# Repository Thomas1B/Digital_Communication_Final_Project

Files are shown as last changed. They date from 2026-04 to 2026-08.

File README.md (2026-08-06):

# ECET 251 Digital Communications — Final Project

**Camosun College — Trades & Technology — Winter 2026**

## Overview

A wireless link between two Arduinos over a 433 MHz ASK "transparent" RF module pair. The transmitter reads a potentiometer, Manchester-encodes the value along with a checksum, and sends it over the air at 300 baud. The receiver decodes the signal, verifies the checksum, and uses the value to set the brightness of an LED via PWM.

All data processing (encoding, framing, error detection) is done in software on the microcontrollers — the RF modules just carry the baseband signal.

## How it works

**Transmitter (`TX.ino`)**
- Reads a potentiometer on `A7`, mapped from the 10-bit ADC range down to 8 bits.
- On a button press (pin 3), builds a 3-byte message: `[length, pot value, checksum]`, where the checksum is the sum of the first two bytes.
- Sends the array via `man.transmitArray()` at `MAN_300` (300 baud) on pin 9.
- Green LED (pin 4) indicates the system is ready to transmit; blue LED (pin 5) flashes to confirm a transmission was sent.
- A 2-second cooldown between transmissions prevents button-mash spamming.

**Receiver (`RX.ino`)**
- Listens on pin 2 via `man.beginReceiveArray()`.
- On receipt of a complete 3-byte message, recalculates the checksum from the first two bytes and compares it to the third.
- If it matches, the potentiometer value is written out as a PWM signal to an LED on pin 5 (brightness control) and a success counter increments; otherwise the message is dropped and an error counter increments.
- Green status LED (pin 4) shows receiver activity, dimming briefly while a message is processed.

**Manchester encoding (`manchester.h` / `Manchester.cpp`)**
- Third-party library ([mchr3k/arduino-libs-manchester](https://github.com/mchr3k/arduino-libs-manchester)) used for the Manchester encode/decode and timer-based bit recovery on the ATmega328.
- Each transmission begins with a training preamble (14 zero-bits + a start bit) so the receiver's AGC can lock onto the signal before the actual payload is decoded.

## Files

| File | Description |
|---|---|
| `TX.ino` | Transmitter sketch (potentiometer read, button trigger, message send) |
| `RX.ino` | Receiver sketch (message decode, checksum check, LED PWM output) |
| `manchester.h` | Manchester library header (third-party, see credit above) |
| `Manchester.cpp` | Manchester library implementation (third-party, see credit above) |
| `ECET_251_FINAL_REPORT.docx` | Full project report/datasheet (block diagram, schematics, RF characteristics, calculations) |
| `ECET251_Final_Project_Overview_-_2026W.pdf` | Original assignment/rubric from the instructor |

## Hardware

- 2x Arduino (or compatible ATmega328-based board)
- 433 MHz ASK TX/RX module pair
- Potentiometer, pushbutton, status/output LEDs, pull-down and current-limiting resistors, smoothing capacitors

See the full report for the bill of materials, schematics, and measured RF characteristics (bandwidth, EIRP, minimum electric field at the receiver, bit error rate, etc.).

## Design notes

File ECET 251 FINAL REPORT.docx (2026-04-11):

# ECET 251 FINAL REPORT

Members: Faith Thurrott, Thomas Bourgeois, Andrew Goertzen

Instructor: Phil Vreugdenhil

Date: April 10th, 2026

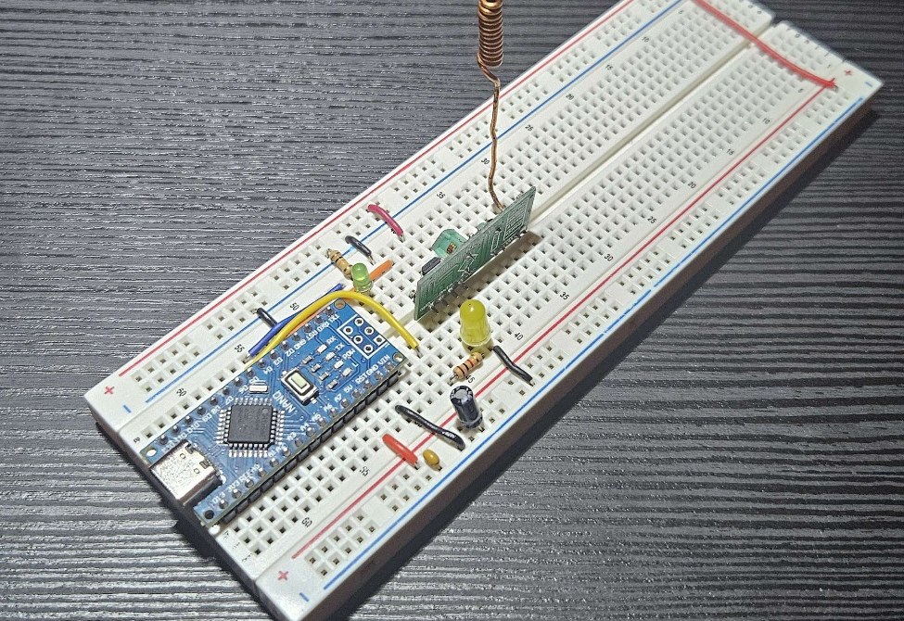
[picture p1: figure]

Figure 1: Receiver Circuit

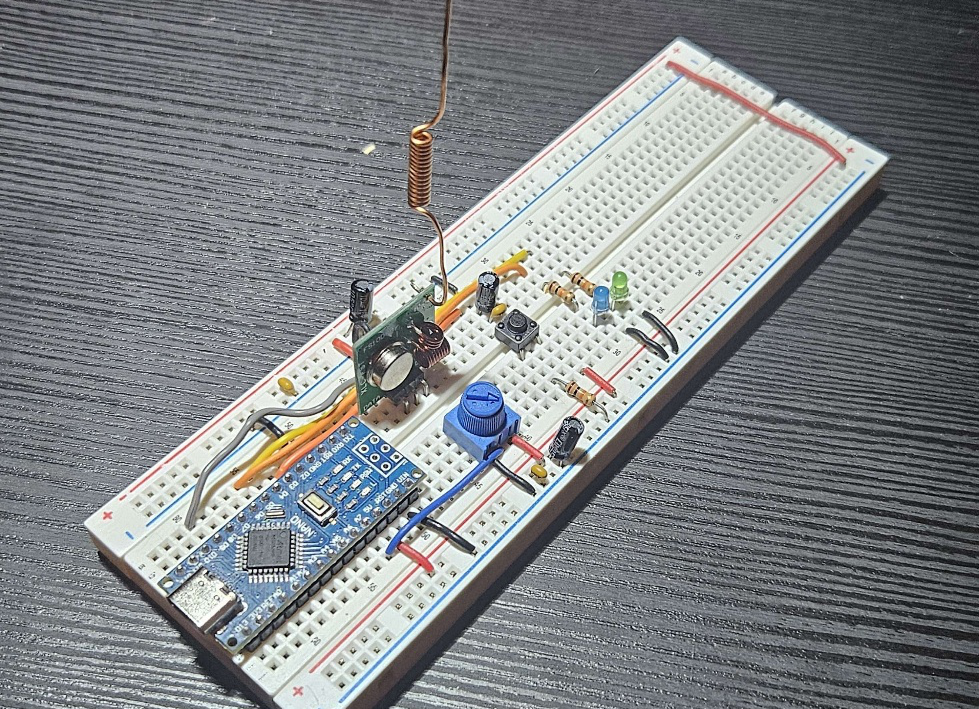
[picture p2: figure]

Figure 2 :Transmitter Circuit

# Project Overview

- Create a wireless system using a microprocessor and TX, Rx modules
- Create a protocol for the system
- Test the communication system
- Document the system

# Project GitHub Repo

https://github.com/Thomas1B/Digital_Communication_Final_Project

# System Description

The following block diagram shows the overall structure of the system, including the main components and signal flow between the transmitter (Tx) and receiver (Rx). The dotted lines represent power, the dashed line represent wireless transmission, and the solid lines represent signals between components.

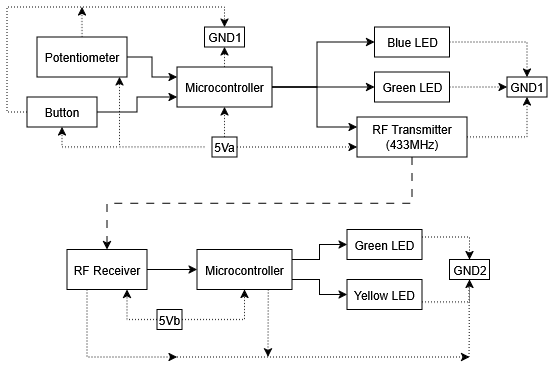
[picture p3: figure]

Figure 3 System Block Diagram

Note: 5Va, 5Vb, GND1, and GND2 are to signify that these two systems are powered separately. They can be power via the USB connection or the Vin pin of the microcontroller.

(5V and GND are the from the internal regulator of the controller).

# Hardware Components

Table 1: BOM: Bill of Materials for Transmitter and Receiver Circuits

Component | Quantity | Specification
Arduino Nano | 2 | 5V microcontroller board. Note 10-bit ADC and 8bit DAC resolution.
Transmitter Module | 1 | 433 MHz RF transmitter module 5Vdc
Receiver Module | 1 | 433 MHz Receiver module. 5Vdc.
Potentiometer | 1 | 10kΩ Pot. (Larger value gives more control)
Button | 1 | Momentary Tactile Switch
LEDS | 4 | 1 Blue LED. 2 Green LEDs, 1 Yellow LED
Resistor | 5 | 1 x 10kΩ, 4 x 1kΩ resistors
Polarized capacitor | 6 | > 4.7uF capacitance
Capacitor | 6 | ≤ 0.1uF non polarized capacitor.

Capacitors are used to smooth the button and potentiometer signals, as well as stabilize power for the transmitter and receiver. While not strictly required, they help reduce noise and improve debouncing. A 10kΩ resistor is used as a pull-down for the button. The 1kΩ resistors can be adjusted to change brightness, make sure the current does not exceed 20 mA. Certain pins of the Arduino are necessary to use, for example PWM pins for the transmitter and to adjust led brightness on the receiver.

# Data Table

Table 2: Collected and Calculated Data

Parameter | Measurement
Bandwidth | 1250Hz
Range limit | 11ft
Min EF at Receiver | 97.4mV/m
Carrier Frequency | 433MHz
Data Rate | 300 Baud Manchester Encoded
Data Format | potentiometer: 10 bit mapped to 8bit, Transmitted data: 3x8bits, Received data: 3x8bits
Operating Voltages | 5 Volts
Power levels | 2.5 Watts
EIRP | 3.36nW
BER | 0.00028%

# Transmitter

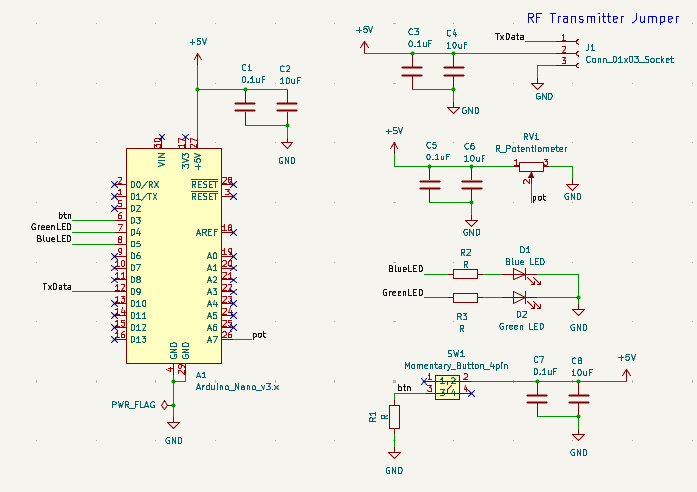
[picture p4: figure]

Figure 4 Schematic of the Transmitter Circuit

The transmitter (Tx) side is designed to read a potentiometer value and send it to the receiver (Rx) using Manchester encoded communication. The potentiometer value is read from an analog pin; when the button is pressed, a 3 x 8-bit byte message is created. The first byte contains the message length, the second byte contains the mapped potentiometer value (since the ADC reads 10bits and the receiver can only transmit 8 bits bytes, also the DAC is only 8bits too), and the third byte contains a checksum for error detection. The checksum is calculated by adding the first two bytes. The data is then sent to the TX module using a PWM pin at a data rate of 300 baud. A green LED indicates when the system is on and ready to transmit, and a blue LED flashes after a message is sent. A timing delay is used so the transmitter does not repeatedly send messages too quickly.

## Transmitter Software Flowchart

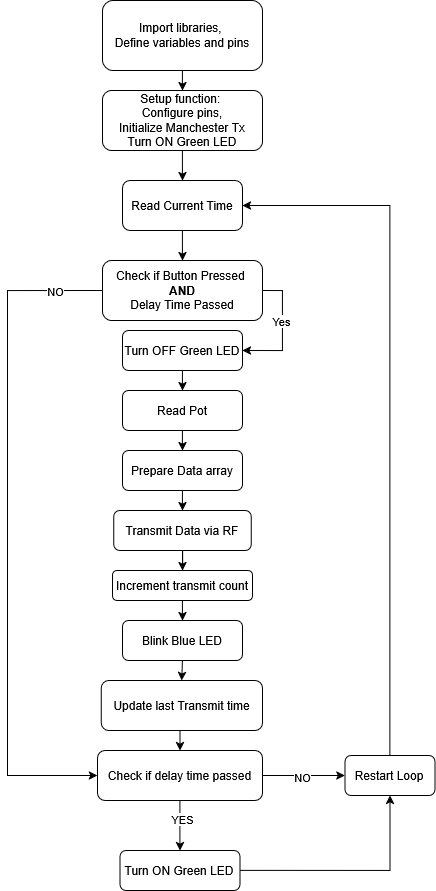
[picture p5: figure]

Figure 6 Transmitter Software Flowchart

# Receiver

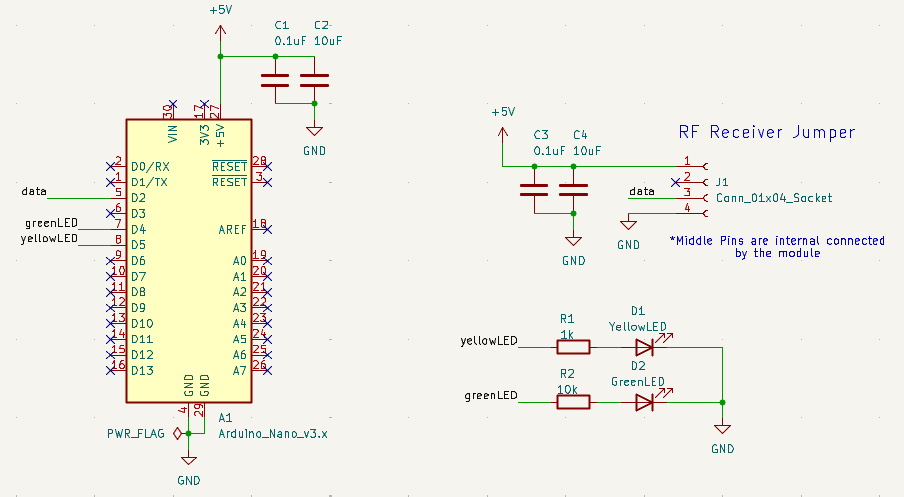
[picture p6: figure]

Figure 5 Schematic of the Receiver Circuit

The receiver side uses Manchester decoding to decode the received 3 8bit byte message through the RF receiver connected to pin 2. The first two bytes contain the transmitted data, and the third byte is used as a checksum for error detection. When a transmission is complete, the code stores the bytes in a buffer, prints the received values to the serial monitor and checks whether the calculated checksum matches the received checksum. If the checksum passes, the system counts it as a successful TX (otherwise ignore it and restart the loop) and uses the second byte to control the brightness of the LED on pin 5 using PWM. A green status LED on pin 4 is used to show the receiver activity, turning off briefly when the message is received being processed, then turning back on when ready for the next message.

## Receiver Software Flowchart

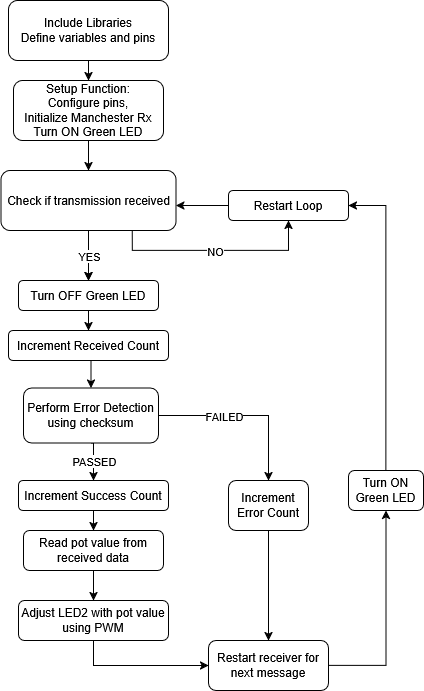
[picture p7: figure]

Figure 7 Receiver Software Flowchart

# Calculations

This section shows the calculations used to evaluate the system’s performance, including EIRP, minimum electric field at the receiver, and bit error rate (BER).

EIRP of TX:

dBm=10log_10 ((P_(sig))/(1mW))→10^(49.69/10) *1mW=10.74nW

V=√(P*R)=√(10.74nW*50Ω)=732.8µV dB=20log_10 ((732.8µV)/(1µV))=57.3dBµV EF(outside antenna)=57.3dBµV+0.29dBµV-17.1dBµV)=40.49dBµV EF=10^(40.49/20) *1µV=105.8µV/m EIRP=4πR^2 *(EF)/Z=4π(3m)^2 *((105.8µV/m)/(377Ω))=3.36nW

Minimum EF at receiver:

EF=√((EIRP*Z)/(4πR^2))=√((3.36nW*377Ω)/(4π3.35m^2))=94.7µV/m

Bit Error Rate:

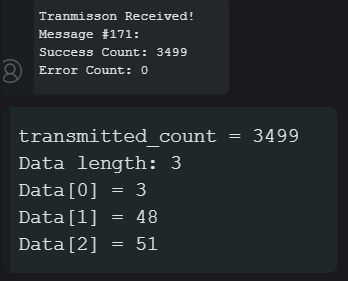
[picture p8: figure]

BER=1/3499=0.00028%

No errors were detected after doing 3499 transmissions. Considering how small of a data packet (3x8bit = 24bits total) is being sent, the chance of an error occurring is quite small.

Figure 8: Serial monitor screen capture.

# Spectrum Analyzer Capture

The following figure shows the frequency spectrum of the transmitted signal as measured using a spectrum analyzer.

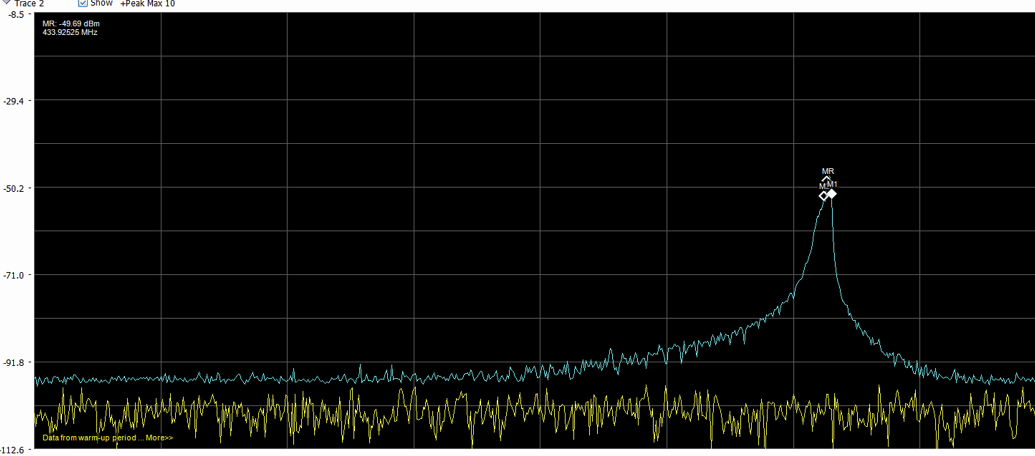
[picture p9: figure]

Figure 9: Spectrum Analyzer capture with data graph.

# Manchester Encoded data packet

The following figure shows the Manchester-encoded data packet, including the structure of the transmitted signal.

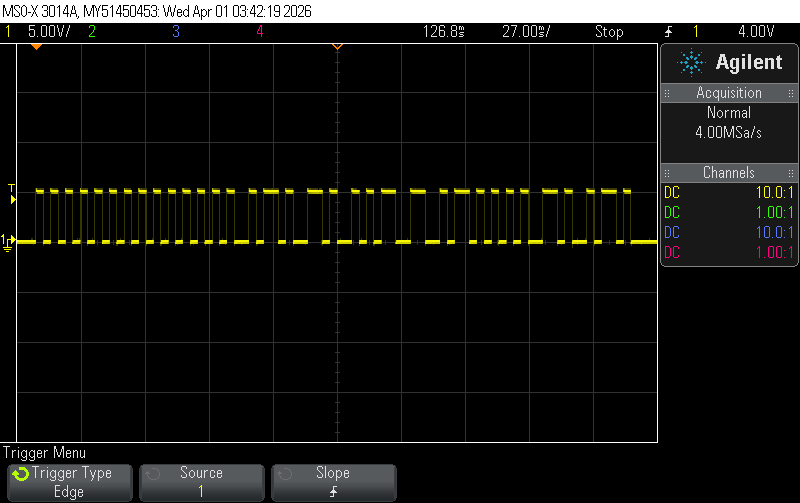
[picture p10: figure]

Figure 10: Oscilloscope capture of Manchester encoded data packet.

# Setbacks and Obstacles

During the development of this project, the main issue we encountered was with the transmitter and receiver modules not reliably communicating with each other.

Initially, the system could not establish a consistent wireless link, even though both the transmitter and receiver were powered and functioning individually. This suggested that the issue was related to the RF modules themselves rather than the microcontroller or code.

To resolve this, various transmitter and receiver modules were tested and a pair that consistently work was chosen. As well as attaching a more suitable antenna. After making these changes, the system was able to successfully transmit and receive data as expected.

Aside from this hardware compatibility issue, the rest of the system functioned as intended with minimal problems. This highlighted the importance of using compatible and reliable RF components in wireless communication systems.

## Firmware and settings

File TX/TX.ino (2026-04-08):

#include <LibPrintf.h>
#include "manchester.h"  // Include Manchester encoding library used for RF transmission

/*
ECET 251 Final Project

Transmitter

This transmitter reads a pot a value and converts it to a voltage, when a button is pressed
the pot value is transmitted using a 433MHz RF module. The receiver reads the data and then 
adjusts an led's brightness accordingly.
*/

/*
  Manchester Transmitter example

  In this example transmitter will send 10 bytes array per transmission
  try different speeds using this constants, your maximum possible speed will
  depend on various factors like transmitter type, distance, microcontroller speed, ...
  MAN_300 0
  MAN_600 1
  MAN_1200 2
  MAN_2400 3
  MAN_4800 4
  MAN_9600 5
  MAN_19200 6
  MAN_38400 7
*/

#define TX_PIN 9     // Pin where the RF transmitter data pin is connected
#define GREEN_LED 4  // Pin connected to the Green LED (indicates system ready)
#define BLUE_LED 5   // Pin connected to the Yellow LED (indicates transmission)
#define button 3     // Pin where the active-HIGH pushbutton is connected
#define pot A7       // Pin where potentiometer is connected.

#define delayTime 2000  // delay time (milliseconds) between transmissions, stops spamming of messages.
uint16_t transmitted_count = 0;

uint8_t data[3] = { 0, 0, 0 };   // Data array that will be transmitted over RF
unsigned long lastTransmit = 0;  // last time data was transmitted.

// ****** Declaring Functions *******
uint8_t get_datalength();

uint8_t get_checkSum();

// ****** Setup Function *******
void setup() {
  printf("Starting Setup\n");

  // Configure button pin as input
  pinMode(button, INPUT);
  // Configure pot pin as input
  pinMode(pot, INPUT);

  // Configure Green LED pin as an output
  pinMode(GREEN_LED, OUTPUT);
  digitalWrite(GREEN_LED, LOW);  // Start with LED off

  // Configure BLUE LED pin as an output
  pinMode(BLUE_LED, OUTPUT);
  digitalWrite(BLUE_LED, LOW);  // Start with LED off


  // Flash both LEDs 5 times at startup as a power-up indicator
  for (byte i = 0; i < 5; i++) {
    digitalWrite(BLUE_LED, HIGH);
    digitalWrite(GREEN_LED, LOW);
    delay(100);
    digitalWrite(GREEN_LED, HIGH);
    digitalWrite(BLUE_LED, LOW);
    delay(100);
  }
  // Required workaround if using 1 MHz ATtiny chips
  //man.workAround1MhzTinyCore();

  // Initialize Manchester transmitter
  // TX_PIN = transmitter data pin
  // MAN_300 = transmission speed (300 baud Manchester encoded)
  man.setupTransmit(TX_PIN, MAN_300);

  Serial.begin(9600);
  printf("Setup Done\n");
  printf("Main Loop now running:\n");
}

// ****** Main Loop *******
void loop() {

  unsigned long now = millis(); // current time

  // If button has been pressed AND the allocated time has passed.
  // This is to stop spamming of button presses.
  if (digitalRead(button) && now - lastTransmit >= delayTime) {
    uint16_t pot_value = analogRead(pot);  // reading pot

    // turn green off to show button pressed.
    digitalWrite(GREEN_LED, LOW);

    // preparing data array for transmission
    data[0] = get_datalength();
    data[1] = map(pot_value, 0, 1023, 0, 255);
    data[2] = get_checkSum();

    // transmitting data
    man.transmitArray(get_datalength(), data);
    transmitted_count++;

    printf("transmitted_count = %d\n", transmitted_count);
    printf("Data length: %d\n", get_datalength());
    for (int i = 0; i < get_datalength() - 1; i++) {
      printf("Data[%d] = %d\n", i, data[i]);
    }
    printf("\n");

    // Blink the Blue LED 5 times to indicate data was transmitted
    for (int i = 0; i < 5; i++) {
      digitalWrite(BLUE_LED, 1);
      delay(100);
      digitalWrite(BLUE_LED, 0);
      delay(100);
    }
    lastTransmit = now;  // updating last transmission time.
  }

  // if allocated time has passed, turn green led on to indicate another transmission can be sent.
  if (now - lastTransmit >= delayTime) {
    digitalWrite(GREEN_LED, HIGH);
  }
}

// ****** Declaring Functions *******
uint8_t get_datalength() {
  /*
  Function to calculate the length of an array.
  Returns a 8bit number

  -> Works by dividing the data size of the array by the size of a data entry.
  */
  return sizeof(data) / sizeof(data[0]);
}

uint8_t get_checkSum() {
  /*
  Function to calculate the checksum value for error detection
  Returns 8bit number

  -> Sums all entries of the array (except for the last entry).
  */
  uint8_t checkSum = 0;
  for (int i = 0; i < get_datalength() - 1; i++) {
    checkSum += data[i];
  }
  return checkSum;
}

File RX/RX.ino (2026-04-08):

#include <LibPrintf.h>
#include "manchester.h"

/*

  Manchester Receiver example
  
  In this example receiver will receive array of 10 bytes per transmittion

  try different speeds using this constants, your maximum possible speed will 
  depend on various factors like transmitter type, distance, microcontroller speed, ...

  MAN_300 0
  MAN_600 1
  MAN_1200 2
  MAN_2400 3
  MAN_4800 4
  MAN_9600 5
  MAN_19200 6
  MAN_38400 7

*/

#define RX_PIN 2     // pin connected to receiver
#define GREEN_LED 4  // GREEN LED for system status
#define LED_PIN 5    // PWM pin connected to LED (for controlling brightness)

#define BUFFER_SIZE 3
uint8_t buffer[BUFFER_SIZE];

uint16_t Rx_num = 0;
uint16_t error_count = 0;
uint16_t success_count = 0;

// ******* Declaring Function *******
void ledController();
void checksum();

// ******* Setup Function *******
void setup() {
  Serial.begin(1200);
  printf("Setup Started\n");
  pinMode(GREEN_LED, OUTPUT);
  pinMode(LED_PIN, OUTPUT);

  man.setupReceive(RX_PIN, MAN_300);
  man.beginReceiveArray(BUFFER_SIZE, buffer);

  analogWrite(LED_PIN, 0);
  digitalWrite(GREEN_LED, HIGH);
  printf("Setup Finished\n");
  printf("Main Loop now running\n");
}

// ******* Main Loop *******
void loop() {
  if (man.receiveComplete()) {  // Check if a transmission has been received
    Rx_num++;
    digitalWrite(GREEN_LED, LOW);  // Turn off LED to indicate processing
    printf("\nTranmisson Received!\n");
    printf("Message #%d:\n", Rx_num);

    // Print received buffer contents
    for (int i = 0; i < BUFFER_SIZE; i++) {
      printf("Buffer[%d] = %u\n", i, buffer[i]);
    }
    printf("end of message.\n");

    checksum();  // Validate received data using checksum (LED function is called in this function)

    man.beginReceiveArray(BUFFER_SIZE, buffer);  // Restart receiver for next message
    delay(250);
    digitalWrite(GREEN_LED, HIGH);  // Indicate ready for next message
  }
}

// ******* Defining Functions *******
void ledController() {
  // simple function to turn on led.
  uint8_t pot_value = buffer[1];
  analogWrite(LED_PIN, pot_value);
}

void checksum() {
  /* 
    Performing error detection using a checksum.
      If passed -> call LED function.
      if failed -> ignore and restart loop.
  */

  uint8_t calculatedChecksum = 0;

  // Sum all bytes except the last (which is the received checksum)
  for (int i = 0; i < BUFFER_SIZE - 1; i++) {
    calculatedChecksum += buffer[i];
  }

  printf("Cal. checksum = %u\n", calculatedChecksum);
  printf("Rec. checksum = %u\n", buffer[BUFFER_SIZE - 1]);

  // Compare calculated checksum with received checksum
  if (buffer[BUFFER_SIZE - 1] == calculatedChecksum) {
    // passed
    success_count++;
    ledController();
  } else {
    // failed
    error_count++;
  }
  printf("Success Count: %d\n", success_count);
  printf("Error Count: %d\n", error_count);
}

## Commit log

2026-03-08 adding schematics
    [Circuits.PrjPcb, transmitter.SchDoc]
2026-03-09 created Altium schematic for transmitter
    [Circuits.PrjPcb, Circuits.SCHLIB, TransmitterBOM.xlsx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]
2026-03-09 started schematic for receiver
    [receiver.SchDoc, transmitter.SchDoc]
2026-03-09 fixed PWM issue, using wrong pin
    [RX.ino]
2026-03-15 changed transmitting pin
2026-03-17 circuits anaylsys
    [transmitter.SchDoc]
2026-04-01 doing Bit Error Rate test
    [RX.ino, TX.ino]
2026-04-05 removed bit error rate testing
    [TX.ino]
2026-04-08 add flowcharts of transmitter and receiver code
2026-04-08 updated flowcharts
2026-04-11 moved all flowcharts to a folder
2026-04-11 created new schematics with KiCad
    [RxCircuit.kicad_pcb, RxCircuit.kicad_sch, TxCircuit.kicad_pcb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]
2026-04-11 updated report
    [Circuits.PrjPcb, TransmitterBOM.xlsx, transmitter.SchDoc]
2026-04-11 updated PCB footprint
    [TxCircuit.kicad_sch]
